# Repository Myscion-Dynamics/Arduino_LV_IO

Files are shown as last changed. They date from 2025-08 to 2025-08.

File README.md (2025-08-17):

# Arduino LED Light Controller

This repo is for a simple LED light controller driven by an Arduino nano.
The lights are driven by a constant current LED driver with a range of 5mA - 200mA depending on the resistor installed.
The board can also be reconfigured as a generic io controller with a max current of 5A per channel.

The LED channels use a low side constant current driver and ifn the io configuration it uses a low side switch.

# Board Render

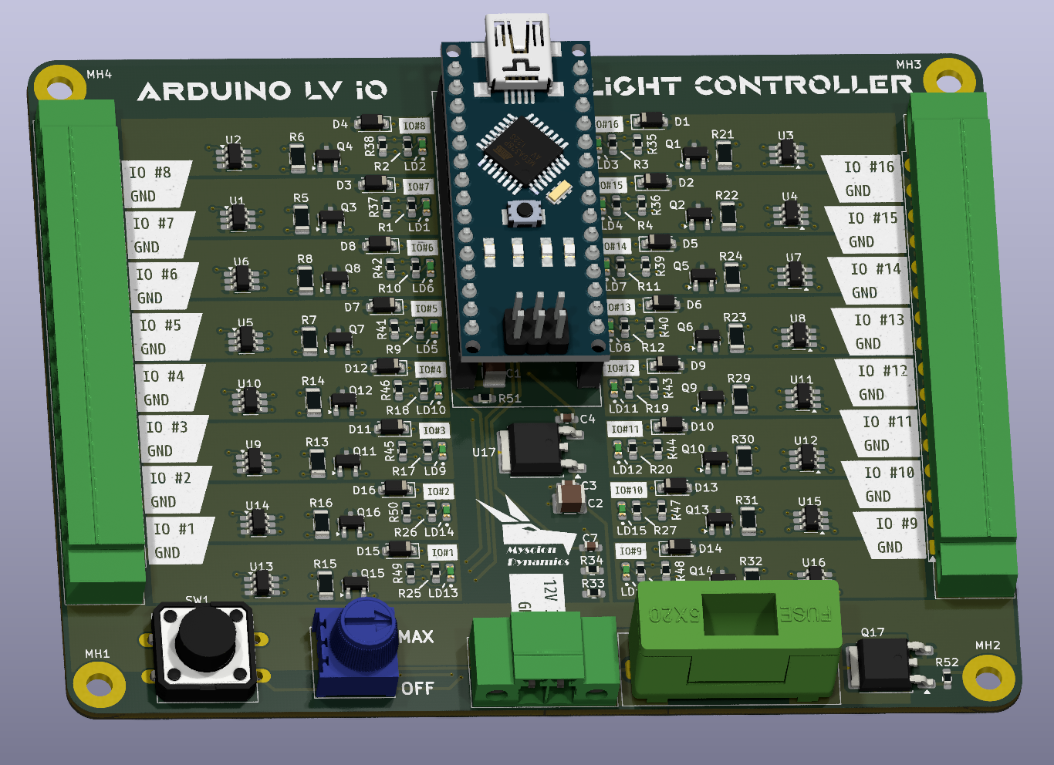
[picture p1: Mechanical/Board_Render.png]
PCB Render


A board mount is included in this repo in the mechanical folder. This should be 3D printed with metric 3M threaded inserts installed.

# Manufactured board

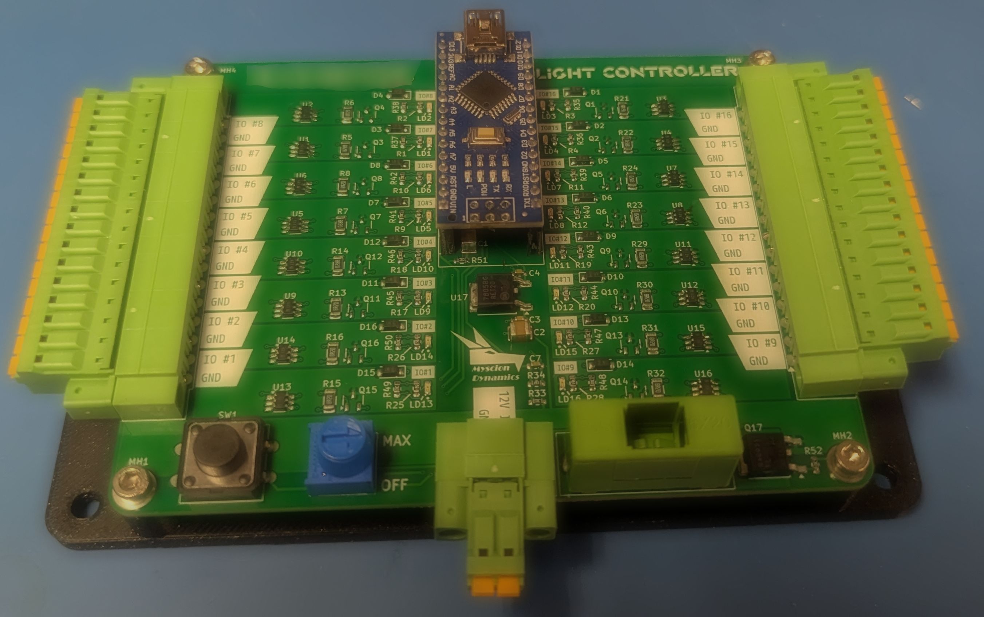
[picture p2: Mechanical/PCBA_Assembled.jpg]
Assembled PCB


# Software
Software for the LED configuration is included. It generates a random pattern of blinking lights.
The brightness is controlled in software and it monitores the input voltage to avoid overdischaring any batteries.
The software runs on an Arduino nano

# Configurations
For the Low side constant current source LED driver popuolate the following IC's 
U1, U2, U3, U4, U5, U6, U7, U8, U9. U10. U11, U12, U13, U14, U15, U15

For the low side switch configuration populate the following transistors
Q1, Q2, Q3, Q4, Q5, Q6, Q7, Q8, Q9, Q10, Q11, Q12, Q13, Q14, Q15, Q16 

Do not install the parts for both configurations at the same time.
It is posible to mix and match configurations are long as care is taken so only one of each is populated on each channel.

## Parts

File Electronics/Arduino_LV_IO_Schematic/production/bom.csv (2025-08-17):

Designator | Footprint | Quantity | Value | LCSC Part #
A1 | Arduino_Nano | 1 | Arduino_Nano_v2 | Arduino NANO
C1, C2 | 1210 | 2 | 10uF | CL32B106KBJNNNE
C3, C4, C7 | 0603 | 3 | 0.1uF | CL10B104KB8NNNC
D1, D10, D11, D12, D13, D14, D15, D16, D2, D3, D4, D5, D6, D7, D8, D9 | D_SOD-123 | 16 | 75V | 1N4148W
FH1 | Wurth_696108003002 | 1 | 20A_MAX | 696108003002
J1, J2 | TE_1x16_3.5mm_1-2842484-6 | 2 | 1-2842484-6 | 1-2842484-6
J3 | TE_1x16_3.5mm_2842484-2 | 1 | 2842484-2 | 2842484-2
LD1, LD10, LD11, LD12, LD13, LD14, LD15, LD16, LD2, LD3, LD4, LD5, LD6, LD7, LD8, LD9 | 0603 | 16 | Green | HSME-C191
MH1, MH4 | MountingHole_3.2mm_M3_Pad | 2 | 3mm
Q1, Q10, Q11, Q12, Q13, Q14, Q15, Q16, Q2, Q3, Q4, Q5, Q6, Q7, Q8, Q9 | SOT-23-3_G-S-D | 16 | DMN3404L-7 | DMN3404L-7
Q17 | TO-252-2 | 1 | SQD40031EL_GE3 | SQD40031EL_GE3
R1, R10, R11, R12, R17, R18, R19, R2, R20, R25, R26, R27, R28, R3, R4, R9 | 0603 | 16 | 560 | RC0603FR-07560RL
R13, R14, R15, R16, R21, R22, R23, R24, R29, R30, R31, R32, R5, R6, R7, R8 | 1206 | 16 | 8.2 | RMCF1206FT8R20
R33, R35, R36, R37, R38, R39, R40, R41, R42, R43, R44, R45, R46, R47, R48, R49, R50, R51, R52 | 0603 | 19 | 10K | RC0603FR-0710KL
R34 | 0603 | 1 | 3.3K | RC0603FR-073K3L
RV1 | Potentiometer_Bourns_3386F_Vertical | 1 | 10K | 3386F-1-103TLF
SW1 | SW_PUSH-12mm_7mm_BLK | 1 | SW_Push | TS14-1212-70-BK-160-SCR-D
U1, U10, U11, U12, U13, U14, U15, U16, U2, U3, U4, U5, U6, U7, U8, U9 | SOT-23-6_Handsoldering | 16 | ~ | BCR421UW6-7
U17 | TO-252-2 | 1 | 3_Pin | MC7805BDTG

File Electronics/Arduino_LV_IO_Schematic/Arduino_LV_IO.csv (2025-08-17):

Reference | Qty | Description | Value | MPN
A1 | 1 | Arduino NANO | Arduino_Nano_v2 | Arduino NANO
C1,C2 | 2 | CAP CER 10UF 50V X7R 1210 | 10uF | CL32B106KBJNNNE
C3,C4,C7 | 3 | CAP CER 0.1UF 50V X7R 0603 | 0.1uF | CL10B104KB8NNNC
D1,D2,D3,D4,D5,D6,D7,D8,D9,D10,D11,D12,D13,D14,D15,D16 | 16 | Diode 75 V 150mA Surface Mount SOD-123 | 75V | 1N4148W
FH1 | 1 | FUSEHOLDER BLOCKS - PCB - CLIP C | 20A_MAX | 696108003002
J1,J2 | 2 | TERM BLOCK HDR 16POS 3.50MM | 1-2842484-6 | 1-2842484-6
J3 | 1 | TERM BLOCK HDR 2POS 3.50MM | 2842484-2 | 2842484-2
LD1,LD2,LD3,LD4,LD5,LD6,LD7,LD8,LD9,LD10,LD11,LD12,LD13,LD14,LD15,LD16 | 16 | LED GREEN DIFFUSED 0603 SMD | Green | HSME-C191
MH1,MH2,MH3,MH4 | 4 | 3mm plated hole | 3mm
P1,P2 | 2 | TERM BLOCK PLUG 16POS 3.50MM | 1-2842480-6 | 1-2842480-6
P3 | 1 | TERM BLOCK PLUG 2POS 3.50MM | 2842480-2 | 2842480-2
Q1,Q2,Q3,Q4,Q5,Q6,Q7,Q8,Q9,Q10,Q11,Q12,Q13,Q14,Q15,Q16 | 16 | N-Channel 30 V 5.8A (Ta) 720mW (Ta) Surface Mount SOT-23-3 | DMN3404L-7 | DMN3404L-7
Q17 | 1 | MOSFET P-CH 30V 100A TO252AA | SQD40031EL_GE3 | SQD40031EL_GE3
R1,R2,R3,R4,R9,R10,R11,R12,R17,R18,R19,R20,R25,R26,R27,R28 | 16 | RES 560 OHM 1% 1/10W SMD | 560 | RC0603FR-07560RL
R5,R6,R7,R8,R13,R14,R15,R16,R21,R22,R23,R24,R29,R30,R31,R32 | 16 | RES 8.2 OHM 1% 1/4W SMD | 8.2 | RMCF1206FT8R20
R33,R35,R36,R37,R38,R39,R40,R41,R42,R43,R44,R45,R46,R47,R48,R49,R50,R51,R52 | 19 | RES 10K OHM 1% 1/10W SMD | 10K | RC0603FR-0710KL
R34 | 1 | RES 3.3K OHM 1% 1/10W SMD | 3.3K | RC0603FR-073K3L
RV1 | 1 | TRIMMER 10K OHM 0.5W PC PIN TOP | 10K | 3386F-1-103TLF
SW1 | 1 | Tactile Switch SPST-NO Top Actuated Through Hole | SW_Push | TS14-1212-70-BK-160-SCR-D
U1,U2,U3,U4,U5,U6,U7,U8,U9,U10,U11,U12,U13,U14,U15,U16 | 16 | IC LED DRVR LIN PWM 500MA SOT-26 | ~ | BCR421UW6-7
U17 | 1 | IC REG LINEAR 5V 1A DPAK | 3_Pin | MC7805BDTG

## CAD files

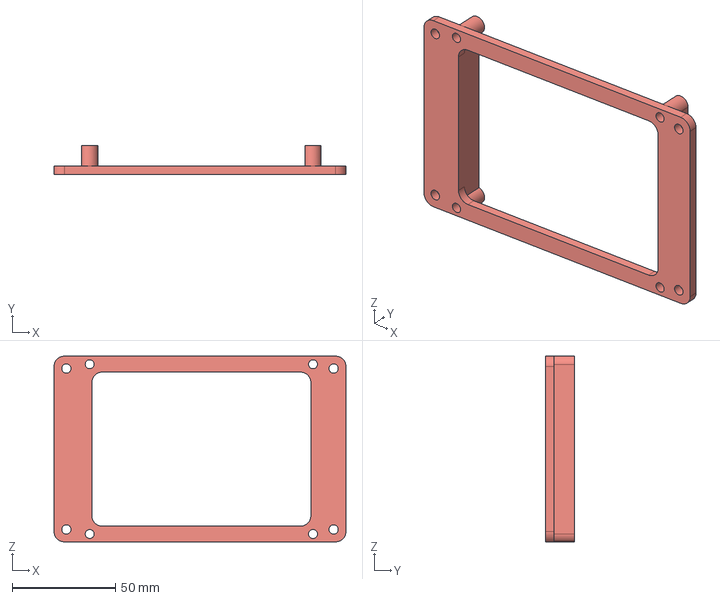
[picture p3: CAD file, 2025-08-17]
Mechanical/Arduino_IO_Mount.step
141.1 x 14.0 x 89.8 mm

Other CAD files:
Mechanical/Arduino_IO_Mount.stl

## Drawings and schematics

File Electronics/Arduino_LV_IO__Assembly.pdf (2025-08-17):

1 | 2 | 3 | 4 | 5 | 6

A

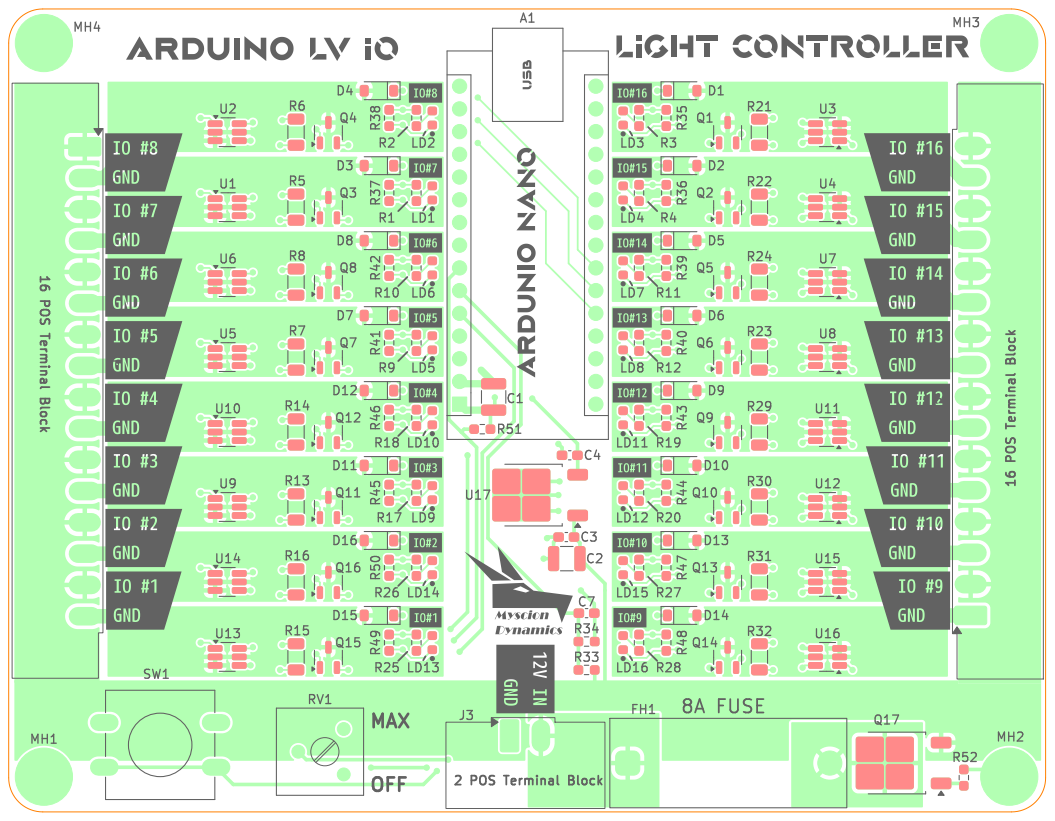
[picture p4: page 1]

A

A

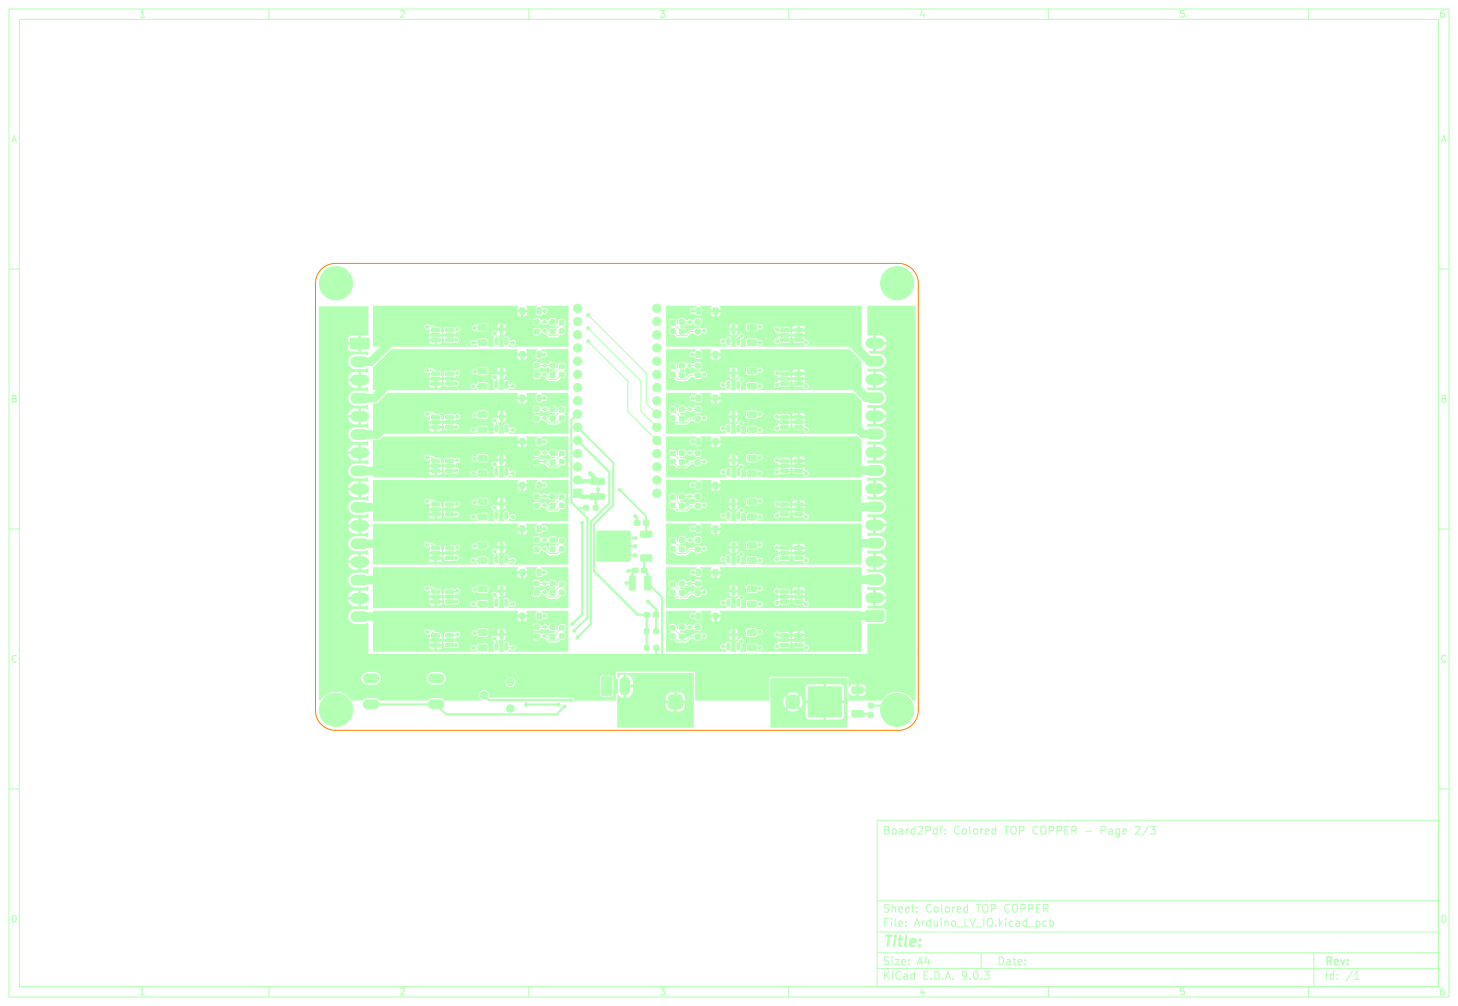
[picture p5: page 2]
D Date: KiCad; E.D.A. 9.0.3 Size: A4; Rev:; Id: /1 Title: File: Arduino_LV_IO.kicad_pcb Sheet: Colored; TOP COPPER; Board2Pdf:; Colored; TOP COPPER -; Page 2/3

A

A

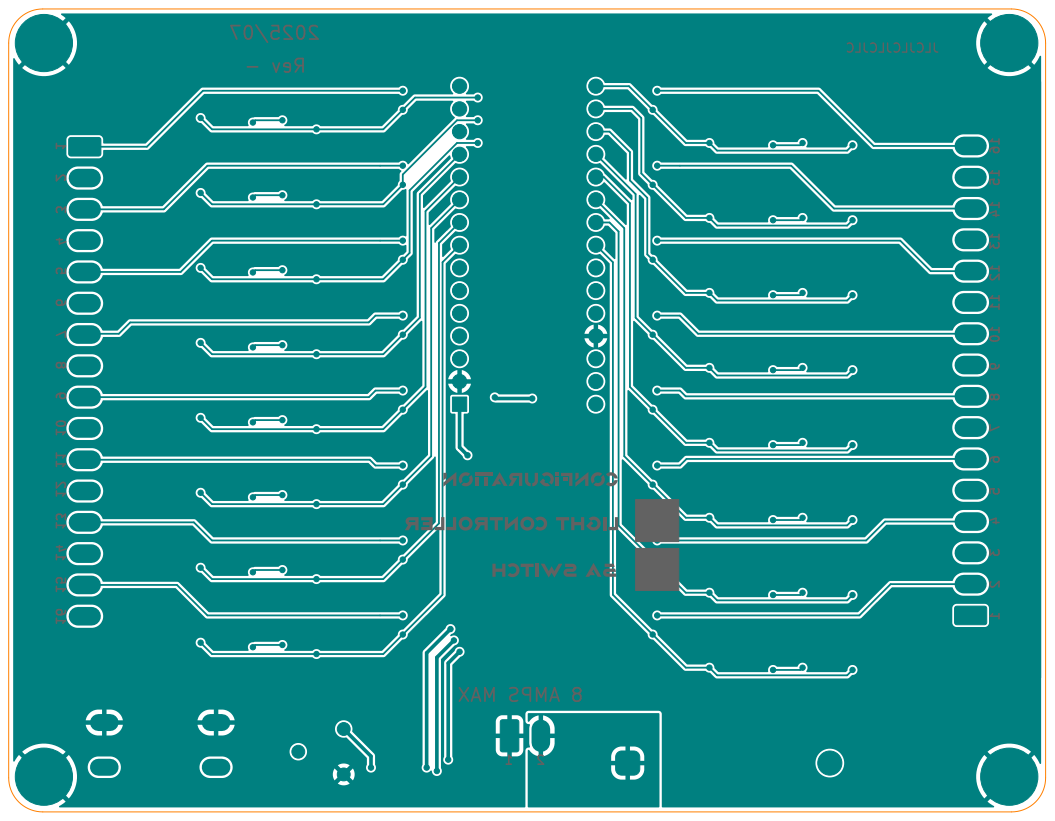
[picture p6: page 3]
D Date: KiCad; E.D.A. 9.0.3 Size: A4; Rev:; Id: /1 Title: File: Arduino_LV_IO.kicad_pcb Sheet: Colored; BOT Board2Pdf:; Colored; BOT -; Page 3/3

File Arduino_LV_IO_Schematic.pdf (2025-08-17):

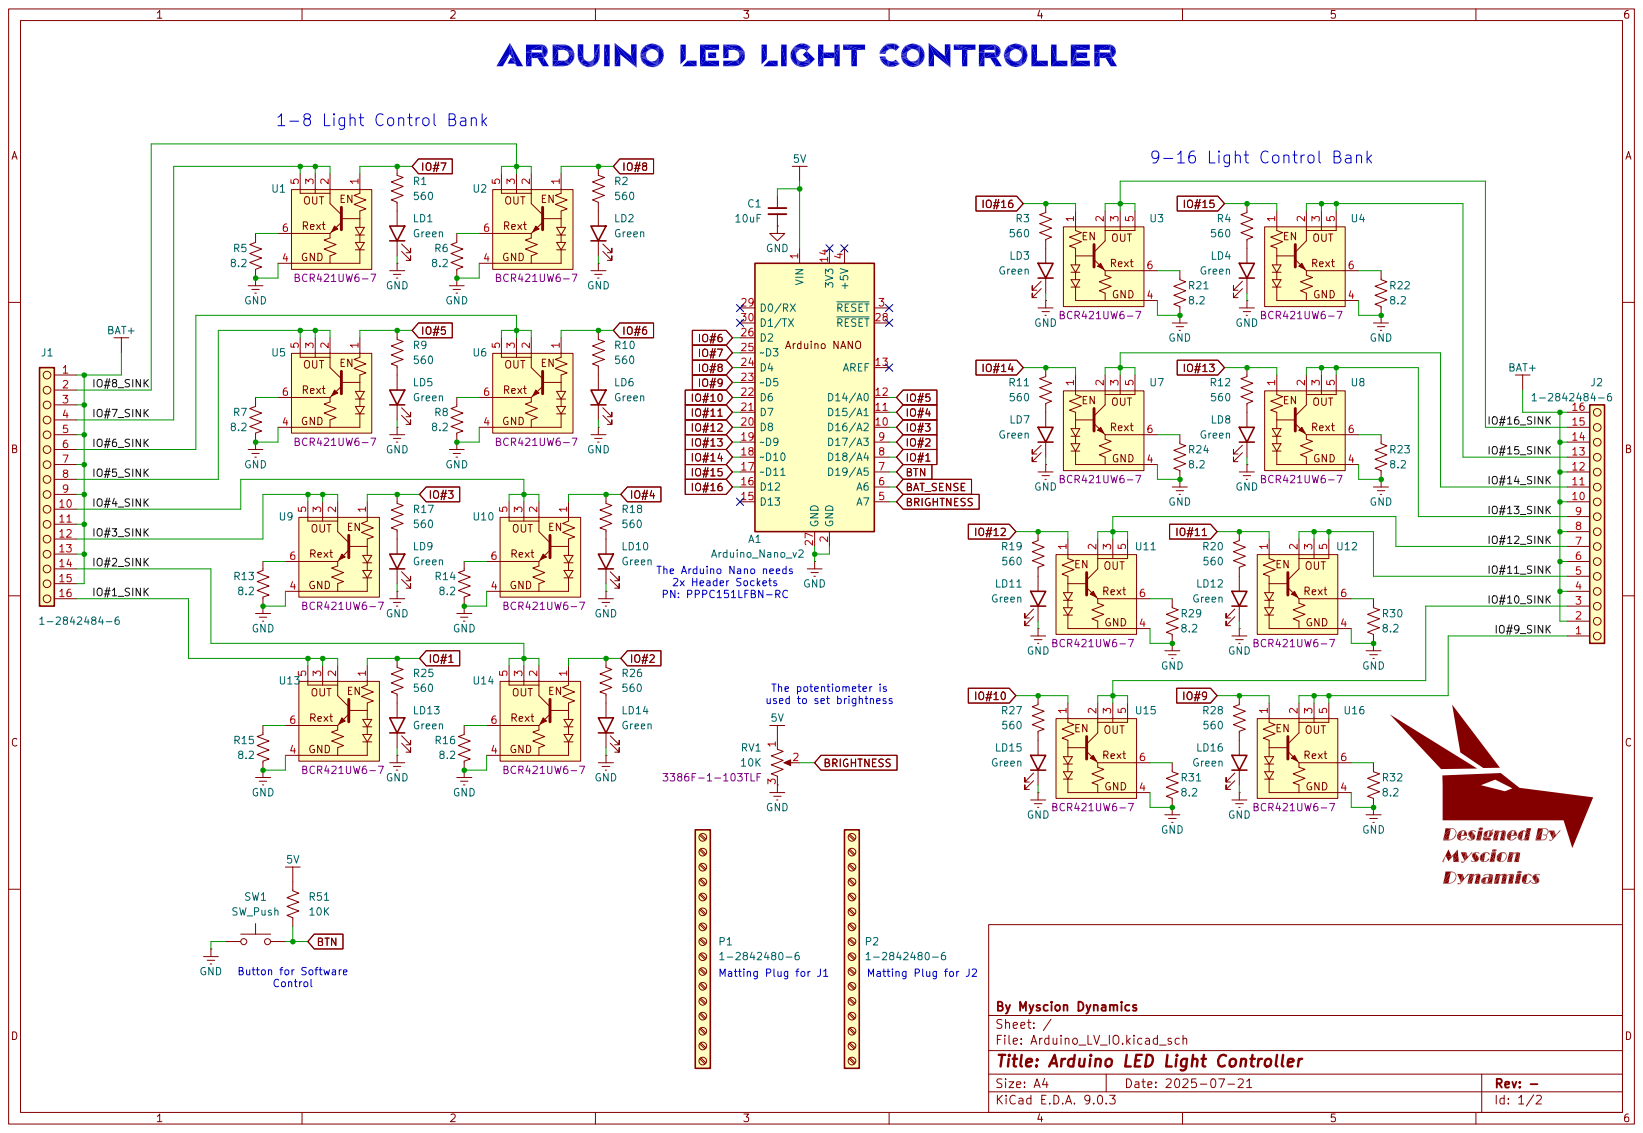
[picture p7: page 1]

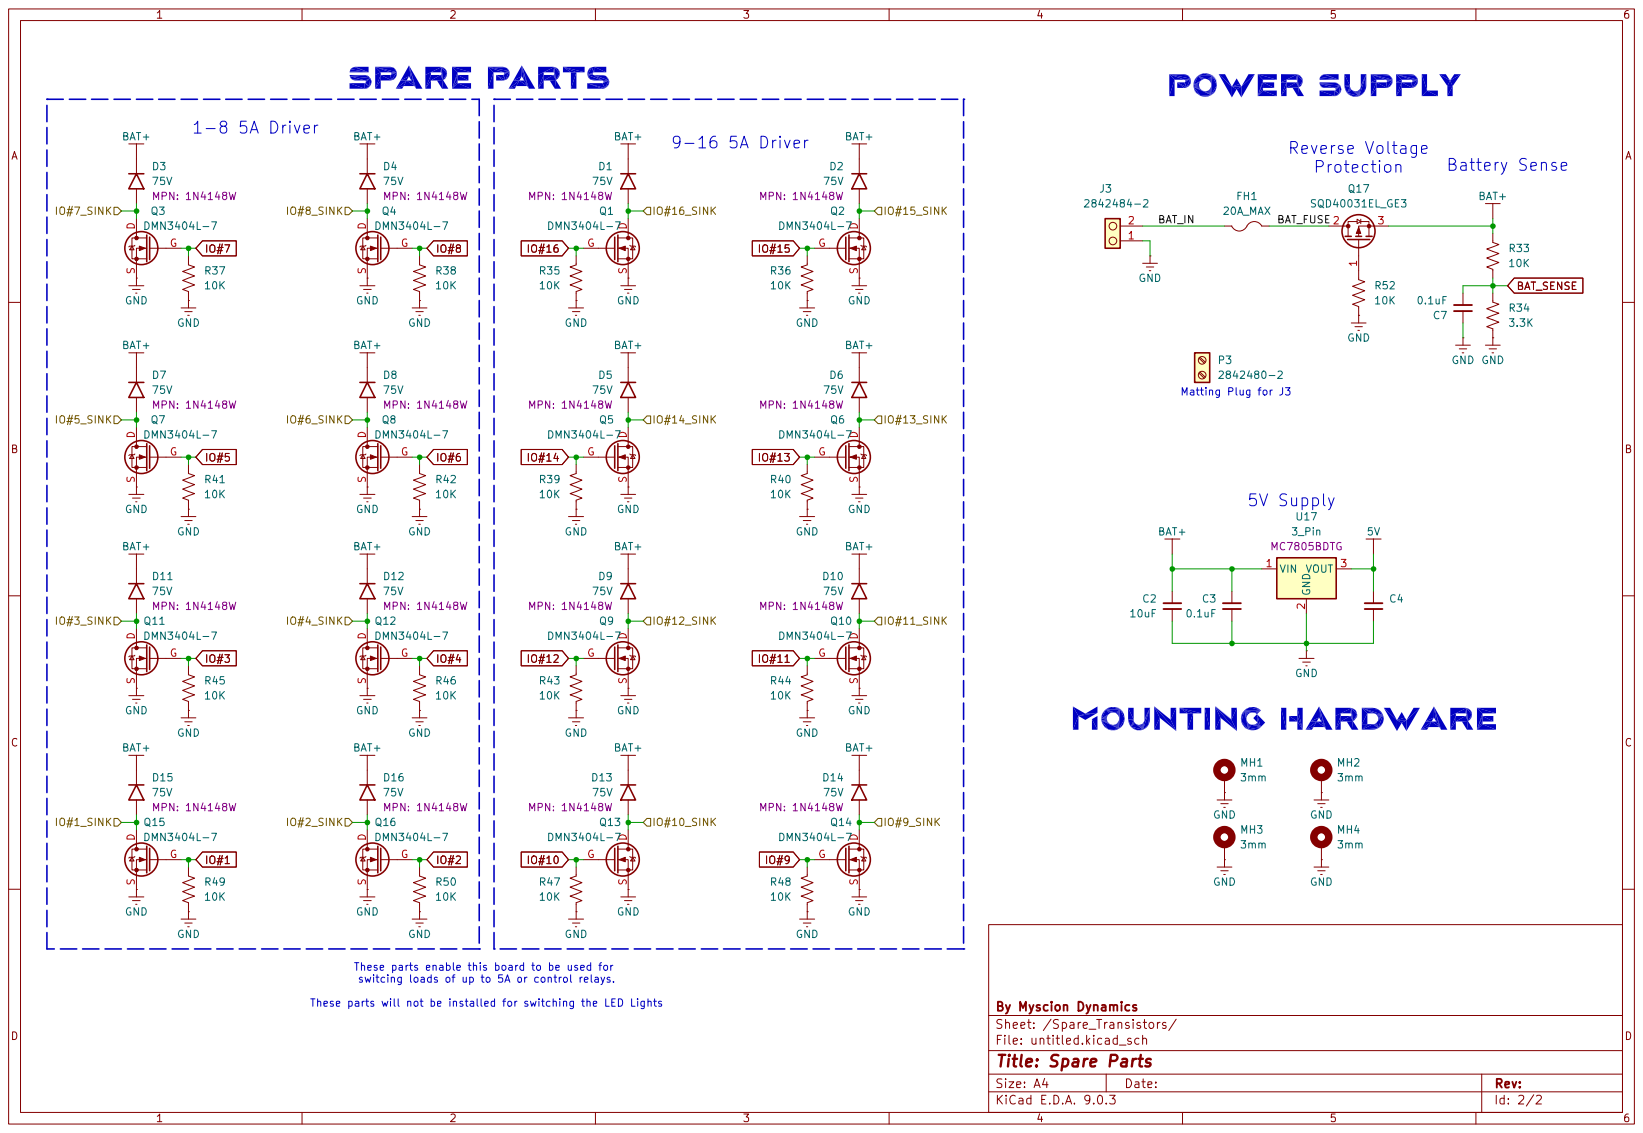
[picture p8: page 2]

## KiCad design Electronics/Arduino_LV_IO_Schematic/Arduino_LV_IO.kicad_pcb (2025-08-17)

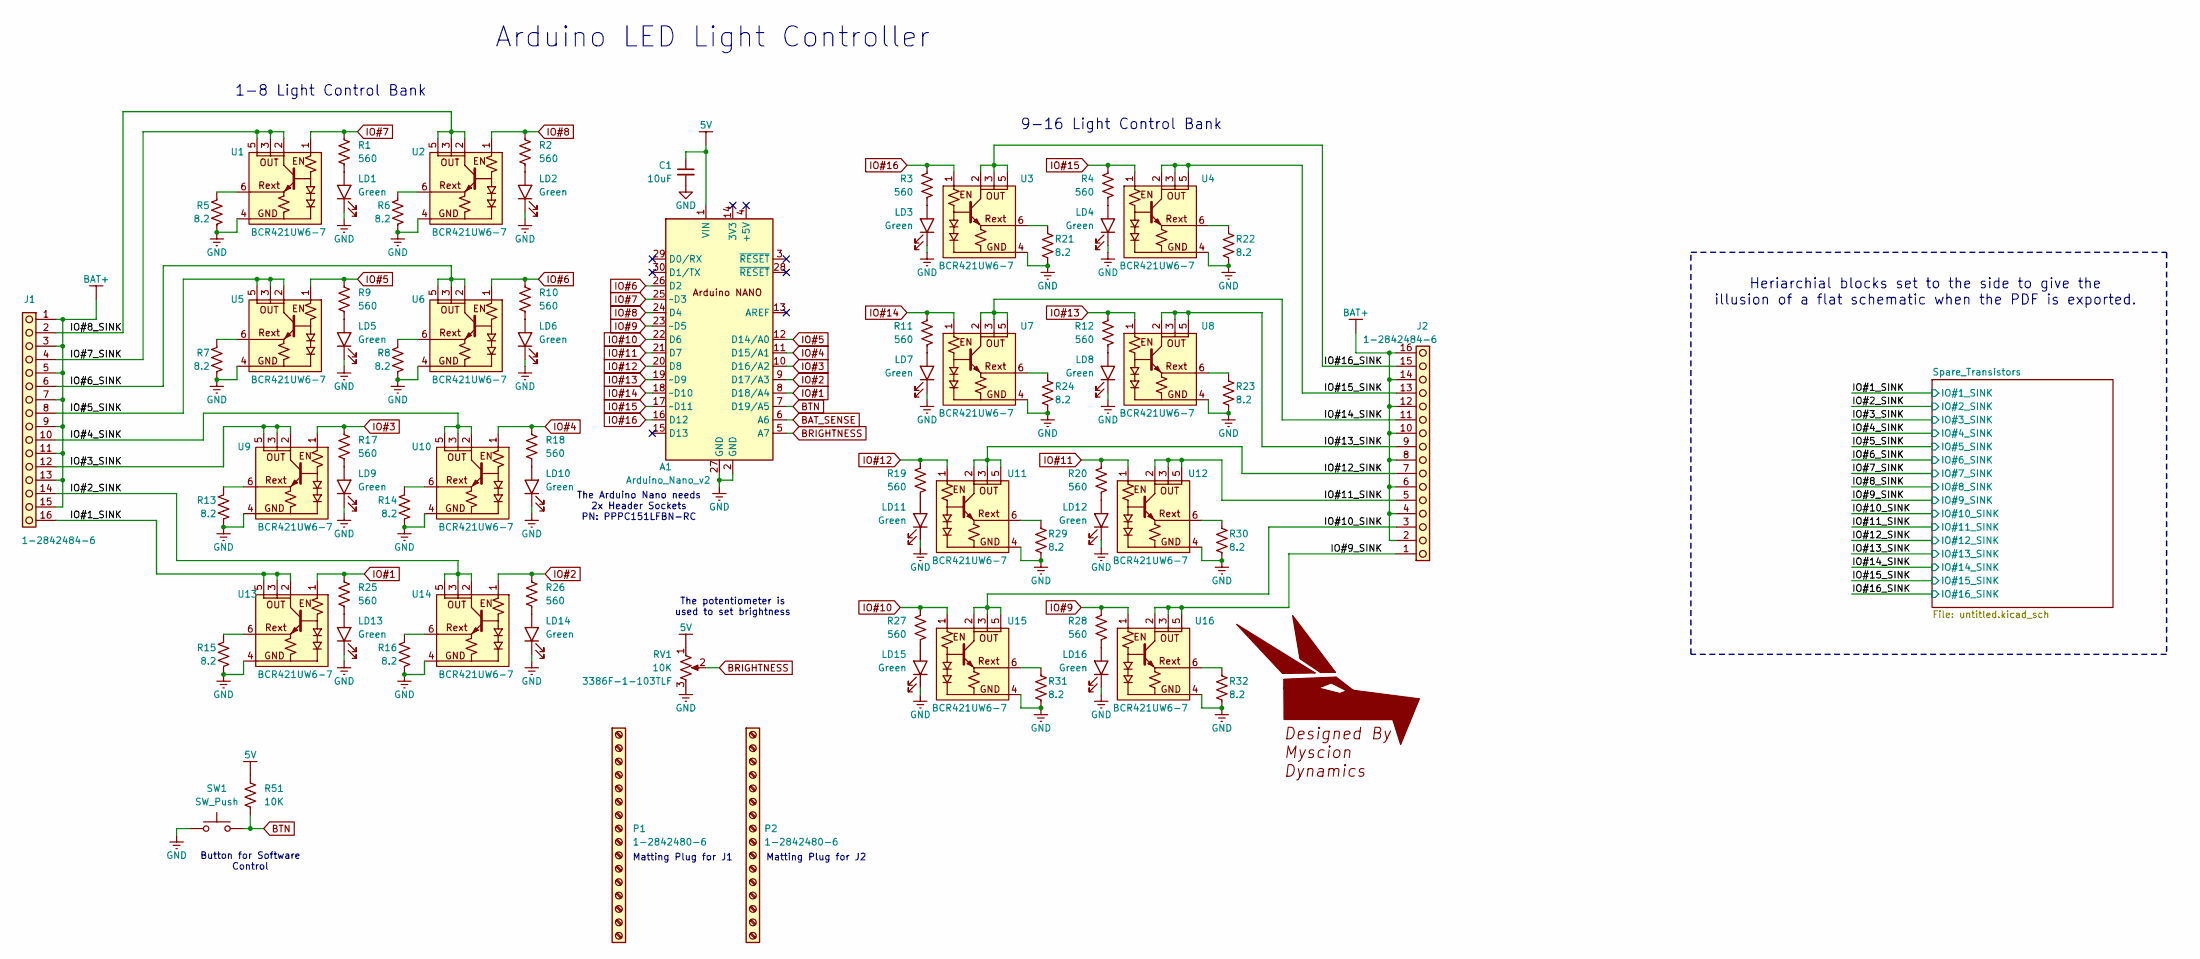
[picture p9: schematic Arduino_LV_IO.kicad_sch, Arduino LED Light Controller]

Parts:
A1: Arduino_Nano_v2; Arduino_Nano; MPN Arduino NANO
C1: 10uF; C_1210_3225Metric; Voltage 50V; Tolerance 10%; MPN CL32B106KBJNNNE
GL1: Myscion_Dynamics_Main
J1, J2: 1-2842484-6; TE_1x16_3.5mm_1-2842484-6; MPN 1-2842484-6
LD1, LD2, LD3, LD4, LD5, LD6, LD7, LD8, LD9, LD10, LD11, LD12, LD13, LD14, LD15, LD16: Green; LED_0603_1608Metric_Green_Cath_Dot; MPN HSME-C191
P1, P2: 1-2842480-6; MPN 1-2842480-6
R1, R2, R3, R4, R9, R10, R11, R12, R17, R18, R19, R20, R25, R26, R27, R28: 560; R_0603_1608Metric_Pad0.98x0.95mm_HandSolder; MPN RC0603FR-07560RL
R5, R6, R7, R8, R13, R14, R15, R16, R21, R22, R23, R24, R29, R30, R31, R32: 8.2; R_1206_3216Metric; MPN RMCF1206FT8R20
R51: 10K; R_0603_1608Metric_Pad0.98x0.95mm_HandSolder; MPN RC0603FR-0710KL
RV1: 10K; Potentiometer_Bourns_3386F_Vertical; MPN 3386F-1-103TLF
SW1: SW_Push; SW_PUSH-12mm_7mm_BLK; MPN TS14-1212-70-BK-160-SCR-D
U1, U2, U3, U4, U5, U6, U7, U8, U9, U10, U11, U12, U13, U14, U15, U16: SOT-23-6_Handsoldering; MPN BCR421UW6-7

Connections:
5V: A1.1 (VIN), C1.1, R51.2, RV1.1; also elsewhere on the board
/IO#1_SINK: J1.16, U13.2 (OUT), U13.3 (OUT), U13.5 (OUT); also elsewhere on the board
/IO#2_SINK: J1.14, U14.2 (OUT), U14.3 (OUT), U14.5 (OUT); also elsewhere on the board
/IO#3_SINK: J1.12, U9.2 (OUT), U9.3 (OUT), U9.5 (OUT); also elsewhere on the board
/IO#4_SINK: J1.10, U10.2 (OUT), U10.3 (OUT), U10.5 (OUT); also elsewhere on the board
/IO#5_SINK: J1.8, U5.2 (OUT), U5.3 (OUT), U5.5 (OUT); also elsewhere on the board
/IO#6_SINK: J1.6, U6.2 (OUT), U6.3 (OUT), U6.5 (OUT); also elsewhere on the board
/IO#7_SINK: J1.4, U1.2 (OUT), U1.3 (OUT), U1.5 (OUT); also elsewhere on the board
/IO#8_SINK: J1.2, U2.2 (OUT), U2.3 (OUT), U2.5 (OUT); also elsewhere on the board
/IO#9_SINK: J2.1, U16.2 (OUT), U16.3 (OUT), U16.5 (OUT); also elsewhere on the board
/IO#10_SINK: J2.3, U15.2 (OUT), U15.3 (OUT), U15.5 (OUT); also elsewhere on the board
/IO#11_SINK: J2.5, U12.2 (OUT), U12.3 (OUT), U12.5 (OUT); also elsewhere on the board
/IO#12_SINK: J2.7, U11.2 (OUT), U11.3 (OUT), U11.5 (OUT); also elsewhere on the board
/IO#13_SINK: J2.9, U8.2 (OUT), U8.3 (OUT), U8.5 (OUT); also elsewhere on the board
/IO#14_SINK: J2.11, U7.2 (OUT), U7.3 (OUT), U7.5 (OUT); also elsewhere on the board
/IO#15_SINK: J2.13, U4.2 (OUT), U4.3 (OUT), U4.5 (OUT); also elsewhere on the board
/IO#16_SINK: J2.15, U3.2 (OUT), U3.3 (OUT), U3.5 (OUT); also elsewhere on the board
BAT+: J1.1, J1.3, J1.5, J1.7, J1.9, J1.11, J1.13, J1.15, J2.2, J2.4, J2.6, J2.8, J2.10, J2.12, J2.14, J2.16; also elsewhere on the board
BAT_SENSE: A1.6 (A6); also elsewhere on the board
BRIGHTNESS: A1.5 (A7), RV1.2
BTN: A1.7 (D19/A5), R51.1, SW1.2
GND: A1.2 (GND), A1.27 (GND), C1.2, LD1.1 (K), LD2.1 (K), LD3.1 (K), LD4.1 (K), LD5.1 (K), LD6.1 (K), LD7.1 (K), LD8.1 (K), LD9.1 (K), LD10.1 (K), LD11.1 (K), LD12.1 (K), LD13.1 (K), LD14.1 (K), LD15.1 (K), LD16.1 (K), R5.2, R6.2, R7.2, R8.2, R13.2, R14.2, R15.2, R16.2, R21.2, R22.2, R23.2, R24.2, R29.2, R30.2, R31.2, R32.2, RV1.3, SW1.1, U1.4 (GND), U2.4 (GND), U3.4 (GND), U4.4 (GND), U5.4 (GND), U6.4 (GND), U7.4 (GND), U8.4 (GND), U9.4 (GND), U10.4 (GND), U11.4 (GND), U12.4 (GND), U13.4 (GND), U14.4 (GND), U15.4 (GND), U16.4 (GND); also elsewhere on the board
IO#1: A1.8 (D18/A4), R25.1, U13.1 (EN); also elsewhere on the board
IO#2: A1.9 (D17/A3), R26.1, U14.1 (EN); also elsewhere on the board
IO#3: A1.10 (D16/A2), R17.1, U9.1 (EN); also elsewhere on the board
IO#4: A1.11 (D15/A1), R18.1, U10.1 (EN); also elsewhere on the board
IO#5: A1.12 (D14/A0), R9.1, U5.1 (EN); also elsewhere on the board
IO#6: A1.26 (D2), R10.1, U6.1 (EN); also elsewhere on the board
IO#7: A1.25 (~D3), R1.1, U1.1 (EN); also elsewhere on the board
IO#8: A1.24 (D4), R2.1, U2.1 (EN); also elsewhere on the board
IO#9: A1.23 (~D5), R28.1, U16.1 (EN); also elsewhere on the board
IO#10: A1.22 (D6), R27.1, U15.1 (EN); also elsewhere on the board
IO#11: A1.21 (D7), R20.1, U12.1 (EN); also elsewhere on the board
IO#12: A1.20 (D8), R19.1, U11.1 (EN); also elsewhere on the board
IO#13: A1.19 (~D9), R12.1, U8.1 (EN); also elsewhere on the board
IO#14: A1.18 (~D10), R11.1, U7.1 (EN); also elsewhere on the board
IO#15: A1.17 (~D11), R4.1, U4.1 (EN); also elsewhere on the board
IO#16: A1.16 (D12), R3.1, U3.1 (EN); also elsewhere on the board
unnamed: LD1.2 (A), R1.2
unnamed: LD2.2 (A), R2.2
unnamed: LD3.2 (A), R3.2
unnamed: LD4.2 (A), R4.2
unnamed: LD5.2 (A), R9.2
unnamed: LD6.2 (A), R10.2
unnamed: LD7.2 (A), R11.2
unnamed: LD8.2 (A), R12.2
unnamed: LD9.2 (A), R17.2
unnamed: LD10.2 (A), R18.2
unnamed: LD11.2 (A), R19.2
unnamed: LD12.2 (A), R20.2
unnamed: LD13.2 (A), R25.2
unnamed: LD14.2 (A), R26.2
unnamed: LD15.2 (A), R27.2
unnamed: LD16.2 (A), R28.2
unnamed: R5.1, U1.6 (Rext)
unnamed: R6.1, U2.6 (Rext)
unnamed: R21.1, U3.6 (Rext)
unnamed: R22.1, U4.6 (Rext)
unnamed: R7.1, U5.6 (Rext)
unnamed: R8.1, U6.6 (Rext)
unnamed: R24.1, U7.6 (Rext)
unnamed: R23.1, U8.6 (Rext)
unnamed: R13.1, U9.6 (Rext)
unnamed: R14.1, U10.6 (Rext)
unnamed: R29.1, U11.6 (Rext)
unnamed: R30.1, U12.6 (Rext)
unnamed: R15.1, U13.6 (Rext)
unnamed: R16.1, U14.6 (Rext)
unnamed: R31.1, U15.6 (Rext)
unnamed: R32.1, U16.6 (Rext)

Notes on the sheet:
1-8 Light Control Bank
Button for Software Control
Matting Plug for J2
Heriarchial blocks set to the side to give the illusion of a flat schematic when the PDF is exported.
Arduino LED Light Controller
The Arduino Nano needs 2x Header Sockets PN: PPPC151LFBN-RC
9-16 Light Control Bank
The potentiometer is used to set brightness
Matting Plug for J1

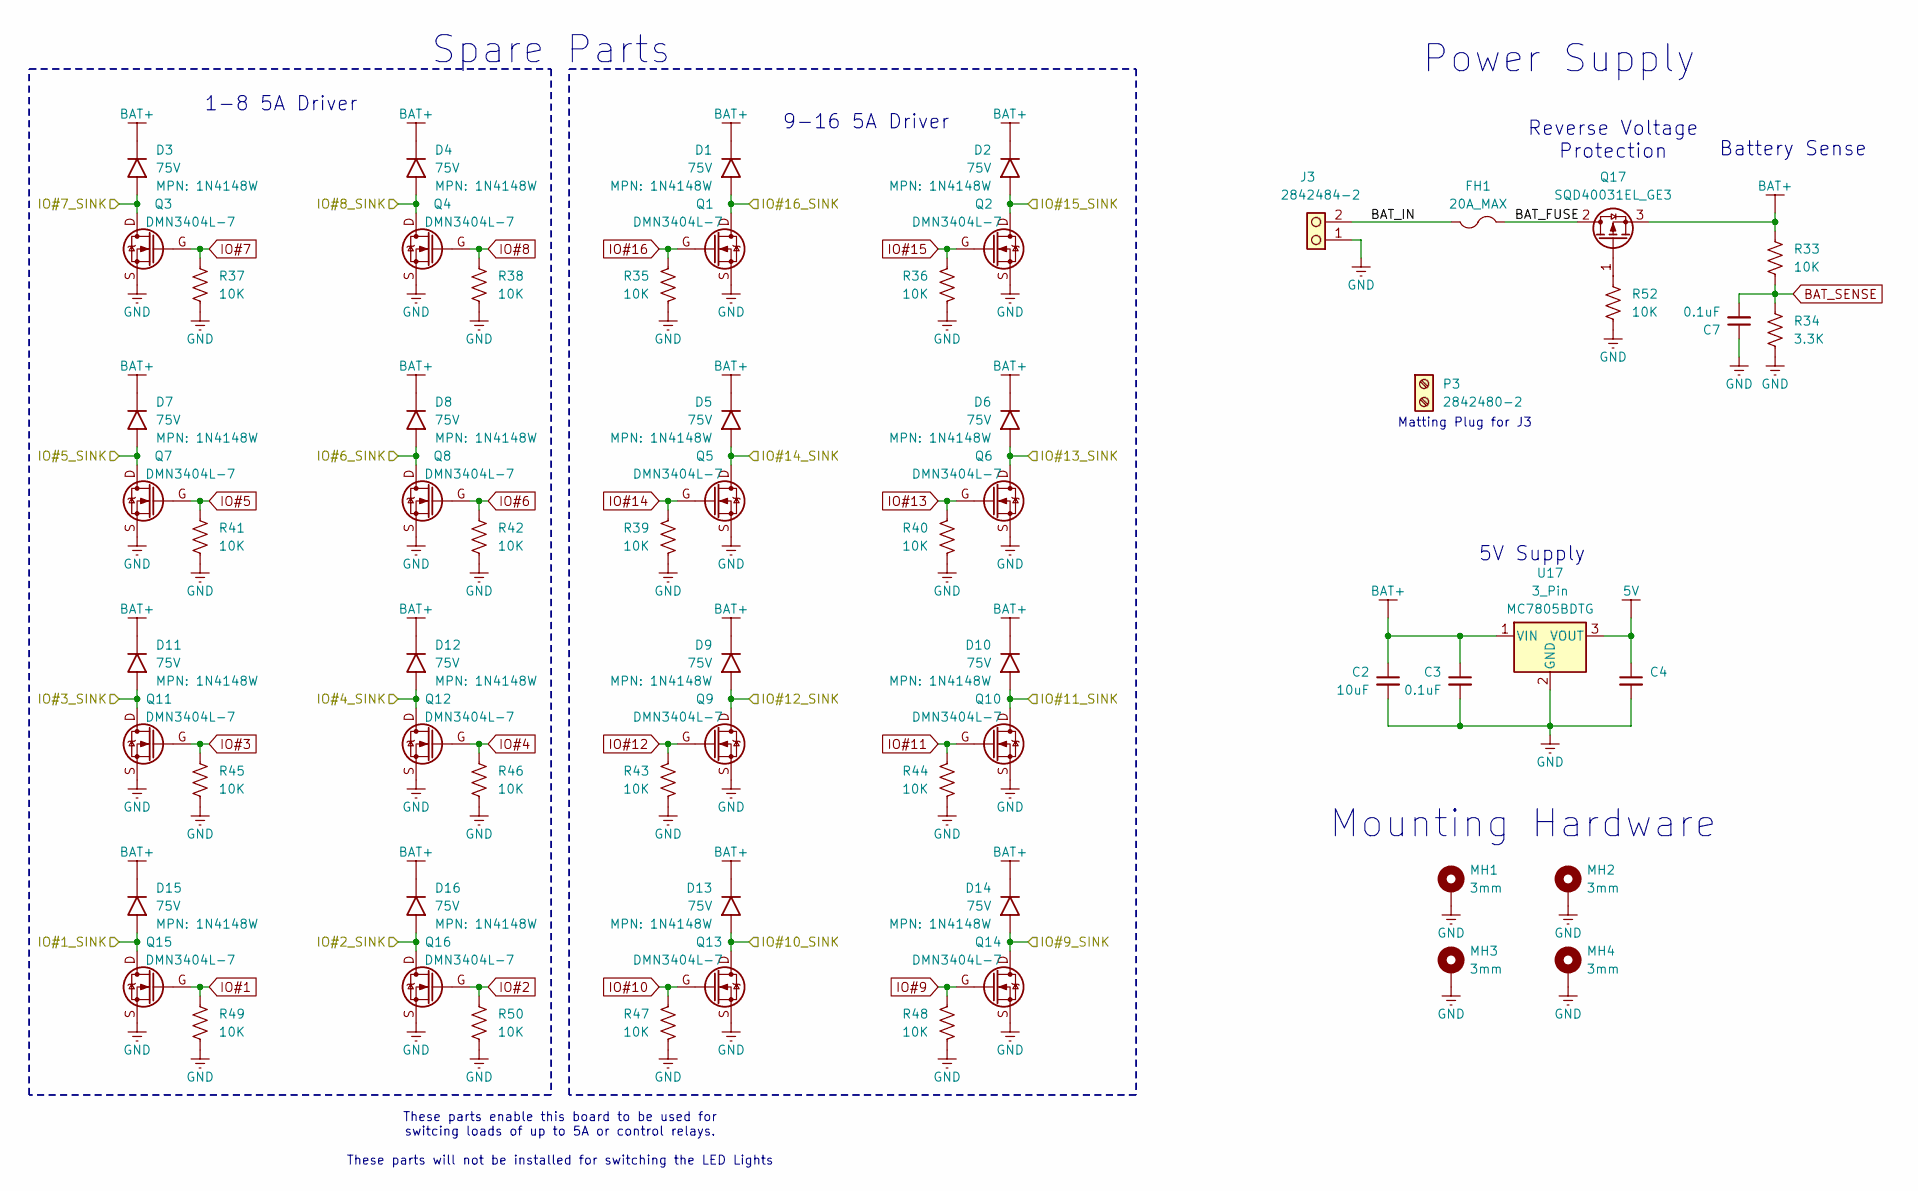
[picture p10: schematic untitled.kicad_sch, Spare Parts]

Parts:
C2: 10uF; C_1210_3225Metric; Voltage 50V; Tolerance 10%; MPN CL32B106KBJNNNE
C3, C4, C7: 0.1uF; C_0603_1608Metric_Pad1.08x0.95mm_HandSolder; Voltage 50V; Tolerance 10%; MPN CL10B104KB8NNNC
D1, D2, D3, D4, D5, D6, D7, D8, D9, D10, D11, D12, D13, D14, D15, D16: 75V; D_SOD-123; MPN 1N4148W
FH1: 20A_MAX; Wurth_696108003002; Voltage Rating 250V; MPN 696108003002
J3: 2842484-2; TE_1x16_3.5mm_2842484-2; MPN 2842484-2
MH1, MH2, MH3, MH4: 3mm; MountingHole_3.2mm_M3_Pad
P3: 2842480-2; MPN 2842480-2
Q1, Q2, Q3, Q4, Q5, Q6, Q7, Q8, Q9, Q10, Q11, Q12, Q13, Q14, Q15, Q16: DMN3404L-7; SOT-23-3_G-S-D; MPN DMN3404L-7
Q17: SQD40031EL_GE3; TO-252-2; MPN SQD40031EL_GE3
R33, R35, R36, R37, R38, R39, R40, R41, R42, R43, R44, R45, R46, R47, R48, R49, R50, R52: 10K; R_0603_1608Metric_Pad0.98x0.95mm_HandSolder; MPN RC0603FR-0710KL
R34: 3.3K; R_0603_1608Metric_Pad0.98x0.95mm_HandSolder; MPN RC0603FR-073K3L
U17: 3_Pin; TO-252-2; MPN MC7805BDTG

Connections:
5V: C4.1, U17.3 (VOUT); also elsewhere on the board
/IO#1_SINK: D15.2 (A), Q15.D; also elsewhere on the board
/IO#2_SINK: D16.2 (A), Q16.D; also elsewhere on the board
/IO#3_SINK: D11.2 (A), Q11.D; also elsewhere on the board
/IO#4_SINK: D12.2 (A), Q12.D; also elsewhere on the board
/IO#5_SINK: D7.2 (A), Q7.D; also elsewhere on the board
/IO#6_SINK: D8.2 (A), Q8.D; also elsewhere on the board
/IO#7_SINK: D3.2 (A), Q3.D; also elsewhere on the board
/IO#8_SINK: D4.2 (A), Q4.D; also elsewhere on the board
/IO#9_SINK: D14.2 (A), Q14.D; also elsewhere on the board
/IO#10_SINK: D13.2 (A), Q13.D; also elsewhere on the board
/IO#11_SINK: D10.2 (A), Q10.D; also elsewhere on the board
/IO#12_SINK: D9.2 (A), Q9.D; also elsewhere on the board
/IO#13_SINK: D6.2 (A), Q6.D; also elsewhere on the board
/IO#14_SINK: D5.2 (A), Q5.D; also elsewhere on the board
/IO#15_SINK: D2.2 (A), Q2.D; also elsewhere on the board
/IO#16_SINK: D1.2 (A), Q1.D; also elsewhere on the board
/Spare_Transistors/BAT_FUSE: FH1.2, Q17.2 (D)
/Spare_Transistors/BAT_IN: FH1.1, J3.2
BAT+: C2.1, C3.1, D1.1 (K), D2.1 (K), D3.1 (K), D4.1 (K), D5.1 (K), D6.1 (K), D7.1 (K), D8.1 (K), D9.1 (K), D10.1 (K), D11.1 (K), D12.1 (K), D13.1 (K), D14.1 (K), D15.1 (K), D16.1 (K), Q17.3 (S), R33.2, U17.1 (VIN); also elsewhere on the board
BAT_SENSE: C7.2, R33.1, R34.1; also elsewhere on the board
GND: C2.2, C3.2, C4.2, C7.1, J3.1, MH1.1, MH2.1, MH3.1, MH4.1, Q1.S, Q2.S, Q3.S, Q4.S, Q5.S, Q6.S, Q7.S, Q8.S, Q9.S, Q10.S, Q11.S, Q12.S, Q13.S, Q14.S, Q15.S, Q16.S, R34.2, R35.1, R36.1, R37.1, R38.1, R39.1, R40.1, R41.1, R42.1, R43.1, R44.1, R45.1, R46.1, R47.1, R48.1, R49.1, R50.1, R52.1, U17.2 (GND); also elsewhere on the board
IO#1: Q15.G, R49.2; also elsewhere on the board
IO#2: Q16.G, R50.2; also elsewhere on the board
IO#3: Q11.G, R45.2; also elsewhere on the board
IO#4: Q12.G, R46.2; also elsewhere on the board
IO#5: Q7.G, R41.2; also elsewhere on the board
IO#6: Q8.G, R42.2; also elsewhere on the board
IO#7: Q3.G, R37.2; also elsewhere on the board
IO#8: Q4.G, R38.2; also elsewhere on the board
IO#9: Q14.G, R48.2; also elsewhere on the board
IO#10: Q13.G, R47.2; also elsewhere on the board
IO#11: Q10.G, R44.2; also elsewhere on the board
IO#12: Q9.G, R43.2; also elsewhere on the board
IO#13: Q6.G, R40.2; also elsewhere on the board
IO#14: Q5.G, R39.2; also elsewhere on the board
IO#15: Q2.G, R36.2; also elsewhere on the board
IO#16: Q1.G, R35.2; also elsewhere on the board
unnamed: Q17.1 (G), R52.2

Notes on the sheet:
Mounting Hardware
Spare Parts
These parts enable this board to be used for switcing loads of up to 5A or control relays. These parts will not be installed for switching the LED Lights
Power Supply
1-8 5A Driver
5V Supply
Reverse Voltage Protection
9-16 5A Driver
Battery Sense
Matting Plug for J3

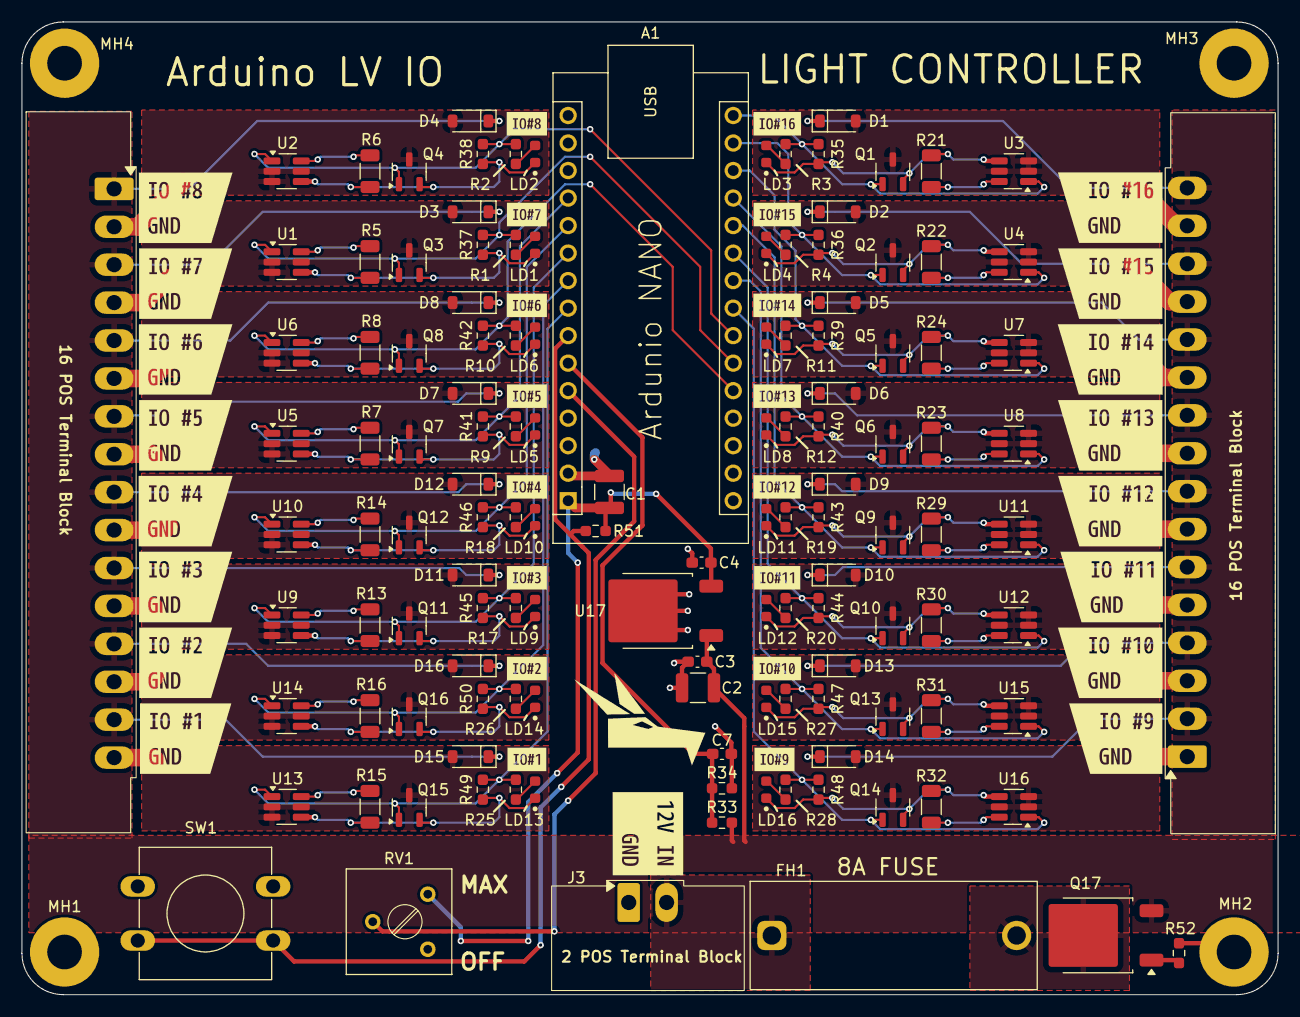
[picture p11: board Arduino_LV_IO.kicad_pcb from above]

Board: 2 copper layers, 116.0 x 89.8 mm, 168 parts (0 on the bottom side), 73 nets.

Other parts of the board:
kibuzzard-68815A57: G***; kibuzzard-68815A57
kibuzzard-68816CB7: G***; kibuzzard-68816CB7
kibuzzard-68818BC9: G***; kibuzzard-68818BC9
kibuzzard-68818BD0: G***; kibuzzard-68818BD0
kibuzzard-68818BD6: G***; kibuzzard-68818BD6
kibuzzard-68818BDE: G***; kibuzzard-68818BDE
kibuzzard-68818BE4: G***; kibuzzard-68818BE4
kibuzzard-68818BEC: G***; kibuzzard-68818BEC
kibuzzard-68818BF4: G***; kibuzzard-68818BF4
kibuzzard-68818BFA: G***; kibuzzard-68818BFA
kibuzzard-68818C0A: G***; kibuzzard-68818C0A
kibuzzard-68818C1C: G***; kibuzzard-68818C1C
kibuzzard-68818C02: G***; kibuzzard-68818C02
kibuzzard-68818C2E: G***; kibuzzard-68818C2E
kibuzzard-68818C16: G***; kibuzzard-68818C16
kibuzzard-68818C23: G***; kibuzzard-68818C23
kibuzzard-68818C28: G***; kibuzzard-68818C28
kibuzzard-68818C34: G***; kibuzzard-68818C34
kibuzzard-688053C9: G***; kibuzzard-688053C9
kibuzzard-688160B8: G***; kibuzzard-688160B8
kibuzzard-688164DF: G***; kibuzzard-688164DF
kibuzzard-688165F4: G***; kibuzzard-688165F4
kibuzzard-688184E6: G***; kibuzzard-688184E6
kibuzzard-6881677E: G***; kibuzzard-6881677E
kibuzzard-6881678F: G***; kibuzzard-6881678F
kibuzzard-6881766C: G***; kibuzzard-6881766C
kibuzzard-6881854C: G***; kibuzzard-6881854C
kibuzzard-6881860D: G***; kibuzzard-6881860D
kibuzzard-68816783: G***; kibuzzard-68816783
kibuzzard-68816789: G***; kibuzzard-68816789
kibuzzard-68818591: G***; kibuzzard-68818591
kibuzzard-68818672: G***; kibuzzard-68818672
kibuzzard-68818677: G***; kibuzzard-68818677

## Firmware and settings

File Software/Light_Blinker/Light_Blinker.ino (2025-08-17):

// Code to control the Arduino LED light blinker
// This code is for the board in it's LED driver configuration
// This code toggles the IO outputs to blink the lights in a random pattern
// The random pattern is generated at the start of the program
// The code reads an analog input that is used to control how bright the LED's are
// The LED brightness is controlled by a software PWM driver
// A button can be used to enable and disable the LED lights
// If the code is not working make sure the potentiometer is set to max and try pressing the button

// These integers are used to asign the pin number to each pin name, this is done to make the code easier to read
const int io1 = 18;  // PC4
const int io2 = 17;  // PC3
const int io3 = 16;  // PC2
const int io4 = 15;  // PC1
const int io5 = 14;  // PC0
const int io6 = 2;   // PD2
const int io7 = 3;   // PD3
const int io8 = 4;   // PD4
const int io9 = 5;   // PD5
const int io10 = 6;  // PD6
const int io11 = 7;  // PD7
const int io12 = 8;  // PB0
const int io13 = 9;  // PB1
const int io14 = 10; // PB2
const int io15 = 11; // PB3
const int io16 = 12; // PB4
const int btn = 19;  // PC5
const int pot_pin = A7;
const int bat_sense_pin = A6;


//These variables can be changed to alter  performance
int threashold = 127; // Range 0-254, Used to compare to random numbers to determine if an LED is on, higher turs on more LED's
int cycleTime = 4000; //Milisceonds per cycle

// Do not change these variables
#define SQLENGTH 800 // How many steps in the sequence, if you go higher than 800 the arduino may run out of ram
uint16_t squence[SQLENGTH]; // Array to hold the seqence data
bool enabled = true; //Set to disabled if battery gets too low

void generateSequence(){// Generate a sequence of random numbers ahead of time
  for(int i = 0; i < SQLENGTH - 1; i++){ // This loops through each item in the array
    squence[i] = 0; // zero out the sequence if this is being re ran a 2nd time
    for(int ran_i = 0; ran_i < 16; ran_i++){ // This loops through the 16 bits on each item in the array
      int ran = random(0, 255);
      if (ran > threashold){ // The random number is between 0 and 255, the threashold can be used to bias the numbers on or off
        squence[i] = squence[i] | (1 << ran_i); // Shift 1 into the position that was just evaluated and store it in the sequence 
      }
    }
  }
}

// IO Range PC0-PC4, PB0-PB4, PD2-PD7
// Button = PC5
void writeSeqeunce(uint16_t data, float brightness, int wait){
  // This fuction takes in "data" and displays it at the speficied "brightness", the funcation uses "wait" to determine how long it should wait
  int ton = 1000 * brightness; // Calculate time on in micro seconds (us)
  int toff = 1000 * (1 - brightness); // Calcuate time off in us
  if (toff < 0) toff = 0; // Make sure time off never goes negative, due to how the potentiometer is sampled brightes can be higher than 100. This is a bit of a clumsy fix


  // For the sake of speed the PORT registers are used instead of the build in arduino digital write
  // Digital write is slow and this operation is much faster. For manual pin control there are three ports. PORTB, PORTC and PORTD
  // Each port has 3 registers, PORTB, PINB, DDRB, the registers control if the pin is on/off, input/output
  uint8_t PB = (data & 0b11111) | (PORTB & 0b11100000);
  uint8_t PC = ((data >> 5) & 0b11111) | (PORTC & 0b11100000);
  uint8_t PD = ((data >> 8) & 0b11111100) | (PORTD & 0b00000011);

  // This is the software brightness function, each cycle is 1 miliscond (ms), the delayMicroseconds command is used for higher accuracy
  for(int i = 0; i < wait; i++){
    PORTB = PB;
    PORTC = PC;
    PORTD = PD;
    delayMicroseconds(ton);

    PORTB &= 0b11100000;
    PORTC &= 0b11100000;
    PORTD &= 0b00000011;
    delayMicroseconds(toff);

    // Check if the button is pressed to turn the LED's off
    uint8_t btn_reg = PINC & 0b00100000;
    if(btn_reg == 0){
      enabled = false;
      delay(2000);
      break;
    }
  }

}

#define BAT_LOW 625 // Cut off at 10.5V, 2.06V on the divider
void checkBattery(){ // This function  checks if the battery is low
  int batt_reading = analogRead(bat_sense_pin);
  
  if(batt_reading < BAT_LOW){ // If the battery is low turn off all the lights
    uint8_t PB = (0b11111) | (PORTB & 0b11100000);
    uint8_t PC = (0b11111) | (PORTC & 0b11100000);
    uint8_t PD = (0b11111100) | (PORTD & 0b00000011);

    for(uint8_t i = 0; i < 5; i++){ // Flash the lights a few times
      PORTB = PB;
      PORTC = PC;
      PORTD = PD;
      delay(300);

      PORTB &= 0b11100000;
      PORTC &= 0b11100000;
      PORTD &= 0b00000011;
      delay(300);
    }

    while(true){ // Keep the lights off but flash them is the user preses the button
      uint8_t btn_reg = PINC & 0b00100000;
      if(btn_reg == 0){
        for(uint8_t i = 0; i < 5; i++){
          PORTB = PB;
          PORTC = PC;
          PORTD = PD;
          delay(300);

          PORTB &= 0b11100000;
          PORTC &= 0b11100000;
          PORTD &= 0b00000011;
          delay(300);
        }
      }
    }
  }
}

// The setup code runs once at the start
void setup() {
  // Configure the output mode of all the pins
  pinMode(io1, OUTPUT);
  pinMode(io2, OUTPUT);
  pinMode(io3, OUTPUT);
  pinMode(io4, OUTPUT);
  pinMode(io5, OUTPUT);
  pinMode(io6, OUTPUT);
  pinMode(io7, OUTPUT);
  pinMode(io8, OUTPUT);
  pinMode(io9, OUTPUT);
  pinMode(io10, OUTPUT);
  pinMode(io11, OUTPUT);
  pinMode(io12, OUTPUT);
  pinMode(io13, OUTPUT);
  pinMode(io14, OUTPUT);
  pinMode(io15, OUTPUT);
  pinMode(io16, OUTPUT);

  // Generate the sequence
  generateSequence();

  // Set the data direction registers. This may not be needed due to the pinMode commands 
  DDRB |= 0b00011111;
  DDRC |= 0b00011111;
  DDRD |= 0b11111100;
}

int sequencePos = 0;
int pot_reading = 0;
float brightness = 0;

// This loop runs continously
void loop() {
  sequencePos++;
  if(sequencePos > SQLENGTH - 1){ // Reset the seqence if it reaches the end
    sequencePos = 0;
  }

  // Read the analog pot and use it to set the brightness value
  pot_reading = analogRead(pot_pin);
  brightness = pot_reading/870.0;
  
  // If enabled run the next step of the seqence
  if(enabled){
    writeSeqeunce(squence[sequencePos], brightness, cycleTime);
  }else{
    for(int i = 0; i < 1000; i++){

      // Check if the button is pressed to turn the LED's back on
      uint8_t btn_reg = PINC & 0b00100000;
      if(btn_reg == 0){
        enabled = true;
        delay(5);
        while(btn_reg == 0){
          btn_reg = PINC & 0b00100000;
        }
        delay(5);

        break;
      }
      delayMicroseconds(1000);
    }
  }

  // Check the battery once per iteration
  checkBattery();

}
